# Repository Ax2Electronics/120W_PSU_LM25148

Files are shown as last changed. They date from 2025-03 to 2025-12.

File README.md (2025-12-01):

Schematic Overview(See PDF export for detailed view)


PCB layers


PCB 3D overview





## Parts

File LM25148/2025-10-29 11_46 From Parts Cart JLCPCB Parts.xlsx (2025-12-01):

Parts Type | JLCPCB Part # | MFR Part # | Description | Unit Price | Qty | Total Price
stock | C25803 | 0603WAF1003T5E | -55℃~+155℃ 100kΩ 100mW 75V Thick Film Resistor ±1% ±100ppm/℃ 0603 Chip Resistor - Surface Mount ROHS | 0.001 | 20 | 0.02 | 1 | 5 | 0.005
buy | C2051924 | IHLP3232DZER2R2M5A | 11.5A 11.7mΩ 14A 2.2uH AEC-Q200 ±20% SMD,8.2x8.2mm Power Inductors ROHS | 0.7305 | 12 | 8.77 | 1 | 5 | 3.6525
stock | C89632 | CL31B106KBHNNNE | 10uF 50V X7R ±10% 1206 Multilayer Ceramic Capacitors MLCC - SMD/SMT ROHS | 0.0539 | 54 | 2.92 | 10 | 5 | 2.695
stock | C863129 | RT0603DRE0749K3L | -55℃~+155℃ 100mW 49.3kΩ Thin Film Resistor ±0.5% ±50ppm/℃ 0603 Chip Resistor - Surface Mount ROHS | 0.0064 | 20 | 0.13 | 1 | 5 | 0.032
stock | C7509568 | 2601-1102 | -60℃~+105℃ 0.14~1.5 1 160V 16~26 17.5A 1x2P 2 2P 3.5mm Gray Right Angle 插件,P=3.5mmm Spring Clamp System Terminal Block ROHS | 1.122 | 11 | 12.35 | 2 | 5 | 11.22
stock | C43922 | 0603B225K160NT | 16V 2.2uF X7R ±10% 0603 Multilayer Ceramic Capacitors MLCC - SMD/SMT ROHS | 0.009 | 20 | 0.18 | 2 | 5 | 0.09
stock | C3289501 | SQJ459EP-T1_GE3 | -55℃~+175℃ 1 P-Channel 108nC@10V 18mΩ@10V 2.5V@250uA 27W 312pF 4.586nF 497pF 52A 60V P-Channel PowerPAKSO-8L MOSFETs ROHS | 0.8715 | 5 | 4.36 | 1 | 5 | 4.3575
stock | C3188828 | LM25148RGYR | -40℃~+125℃ 1 2.2MHz 3.5V~42V 800mV~36V 9.5uA Adjustable Buck Buck External Yes VQFN-24(5.5x3.5) DC-DC Converters ROHS | 1.8195 | 5 | 9.1 | 1 | 5 | 9.0975
stock | C29536843 | IAUCN04S7L028ATMA1 | -55℃~+175℃ 1.578nF 1.8V@15uA 100A 2.82mΩ@10V 24nC@10V 36pF 40V 58W 788pF N-Channel TDSON-8 MOSFETs ROHS | 0.732 | 20 | 14.64 | 4 | 5 | 14.64
stock | C2930101 | FRC0603F4122TS | -55℃~+155℃ 100mW 41.2kΩ 75V Thick Film Resistor ±1% ±100ppm/℃ 0603 Chip Resistor - Surface Mount ROHS | 0.001 | 20 | 0.02 | 1 | 5 | 0.005
stock | C2847583 | MDA1365-100M | 10A 10uH 13A 19.2mΩ ±20% SMD,13.5x12.6mm Inductors (SMD) ROHS | 1.0125 | 5 | 5.07 | 1 | 5 | 5.0625
stock | C25962 | 0603WAF2492T5E | -55℃~+155℃ 100mW 24.9kΩ 75V Thick Film Resistor ±1% ±100ppm/℃ 0603 Chip Resistor - Surface Mount ROHS | 0.0011 | 20 | 0.03 | 1 | 5 | 0.0055
stock | C25811 | 0603WAF2003T5E | -55℃~+155℃ 100mW 200kΩ 75V Thick Film Resistor ±1% ±100ppm/℃ 0603 Chip Resistor - Surface Mount ROHS | 0.0011 | 20 | 0.03 | 1 | 5 | 0.0055
stock | C100771 | CR0603FA1432G | -55℃~+125℃ 100mW 14.3kΩ 50V Thick Film Resistor ±1% ±100ppm/℃ 0603 Chip Resistor - Surface Mount ROHS | 0.0007 | 20 | 0.02 | 1 | 5 | 0.0035
stock | C23184 | 0603WAF4992T5E | -55℃~+155℃ 100mW 49.9kΩ 75V Thick Film Resistor ±1% ±100ppm/℃ 0603 Chip Resistor - Surface Mount ROHS | 0.0011 | 20 | 0.03 | 1 | 5 | 0.0055
stock | C224085 | TPSMB33CA | -65℃~+175℃ 12.2uA 1A@10/1000us 28.2V 37.8V 49.9V 600W@10/1000us Bidirectional IEC 61000-4-2 TVS DO-214AA ESD and Surge Protection (TVS/ESD) ROHS | 0.1467 | 5 | 0.74 | 1 | 5 | 0.7335
stock | C21397 | GRM32ER71E226KE15L | 22uF 25V X7R ±10% 1210 Multilayer Ceramic Capacitors MLCC - SMD/SMT ROHS | 0.2037 | 20 | 4.08 | 4 | 5 | 4.074
stock | C19606 | RVT1V331M1010 | -55℃~+105℃ 10.2mm 10mm 2000hrs@105℃ 330uF 35V ±20% SMD,D10xL10.5mm Aluminum Electrolytic Capacitors - SMD ROHS | 0.1091 | 6 | 0.66 | 1 | 5 | 0.5455
stock | C185817 | RLM25FEER005 | 2W 5mΩ Current Sense Resistor Surface Mount ±1% ±50ppm/℃ 2512 Current Sense Resistors / Shunt Resistors ROHS | 0.0458 | 9 | 0.42 | 1 | 5 | 0.229
stock | C17660 | 0805W8F300KT5E | -55℃~+155℃ 125mW 150V 3Ω Thick Film Resistor ±1% ±200ppm/℃ 0805 Chip Resistor - Surface Mount ROHS | 0.003 | 20 | 0.06 | 1 | 5 | 0.015
stock | C17168 | 0402WGF0000TCE | -55℃~+155℃ 0Ω 50V 62.5mW Thick Film Resistor ±1% ±800ppm/℃ 0402 Chip Resistor - Surface Mount ROHS | 0.0005 | 40 | 0.02 | 6 | 5 | 0.015
stock | C1599 | 0603B182K500NT | 1.8nF 50V X7R ±10% 0603 Multilayer Ceramic Capacitors MLCC - SMD/SMT ROHS | 0.003 | 20 | 0.06 | 1 | 5 | 0.015
stock | C1591 | CL10B104KB8NNNC | 100nF 50V X7R ±10% 0603 Multilayer Ceramic Capacitors MLCC - SMD/SMT ROHS | 0.0026 | 70 | 0.19 | 12 | 5 | 0.156
stock | C152458 | BAT54T1G | -55℃~+125℃ 200mA 2uA@25V 30V 600mA 800mV@100mA SOD-123 Schottky Diodes ROHS | 0.0209 | 9 | 0.19 | 1 | 5 | 0.1045
stock | C15177 | CL21B102KCANNNC | 100V 1nF X7R ±10% 0805 Multilayer Ceramic Capacitors MLCC - SMD/SMT ROHS | 0.009 | 20 | 0.18 | 1 | 5 | 0.045
stock | C101063 | CR0603FA4702G | -55℃~+125℃ 100mW 47kΩ 50V Thick Film Resistor ±1% ±100ppm/℃ 0603 Chip Resistor - Surface Mount ROHS | 0.0013 | 20 | 0.03 | 1 | 5 | 0.0065
overseas_shop | C25905937 | A785MN227M1VLAS023 | 220 µF 35 V Aluminum - Polymer Capacitors Radial, Can - SMD 23mOhm 1000 Hrs @ 150°C | 1.0765 | 10 | 10.77 | 2 | 5 | 10.765
overseas_shop | C3735058 | DZ23C15-E3-08 | Zener Diodes 15 Volt 0.3 Watt 5% | 0.0795 | 268 | 21.31 | 1 | 5 | 0.3975
 |  |  |  |  |  |  |  | comp | 67.9785
 |  |  |  |  |  |  |  | pcb | 7
 |  |  |  |  |  |  |  | assy | 30
 |  |  |  |  |  |  |  |  | 104.9785

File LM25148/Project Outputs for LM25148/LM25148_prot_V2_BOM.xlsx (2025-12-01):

DigiKey Part Number | Mouser Part Number | Comment | Description | Designator | Footprint | LibRef | Quantity | Local price | Total | Manufacturer Product Number | ComponentLink1URL | ComponentLink2URL
565-EMZR500ARA331MJA0GCT-ND |  | 330uF | 330 µF 50 V Aluminum Electrolytic Capacitors Radial, Can - SMD 120mOhm @ 100kHz 2000 Hrs @ 105°C | C1 | CAPAE109103X103M | C000026 | 1 | 200 | 200 | EMZR500ARA331MJA0G | https://www.digikey.com/en/products/detail/chemi-con/EMZR500ARA331MJA0G/5824768
1276-6767-1-ND |  | 10uF | 10 µF ±10% 50V Ceramic Capacitor X7R 1206 (3216 Metric) | C2, C3, C4, C5, C9, C14, C16, C34, C35, C36 | CAP_1206 | C000017 | 10 | 30 | 300 | CL31B106KBHNNNE | https://www.digikey.com/en/products/detail/samsung-electro-mechanics/CL31B106KBHNNNE/5961251
1276-1000-1-ND |  | 0.1uF | 0.1 µF ±10% 50V Ceramic Capacitor X7R 0603 (1608 Metric) | C6, C7, C8, C11, C12, C13, C15, C37 | CAP_0603 | C000018 | 8 | 1.68 | 13.44 | CL10B104KB8NNNC | https://www.digikey.com/en/products/detail/samsung-electro-mechanics/CL10B104KB8NNNC/3886658
490-12731-1-ND |  | 2.2uF | 8 pF ±0.05pF 25V Ceramic Capacitor C0G, NP0 01005 (0402 Metric) | C10, C33 | CAP_0603 | C000014 | 2 | 23.48 | 46.96 | GRM188C71C225KE11D | https://www.digikey.com/en/products/detail/murata-electronics/GRM188C71C225KE11D/4905311
478-KAM15AR71E104KTCT-ND |  | 100nF | 0.1 µF ±10% 25V Ceramic Capacitor X7R 0603 (1608 Metric) | C17, C18, C29, C32 | CAP_0603 | C000007 | 4 | 14.04 | 56.16 | KAM15AR71E104KT | https://www.digikey.com/en/products/detail/kyocera-avx/06033C104K4T2A/8019250
1276-3392-1-ND |  | 22uF | 22 µF ±10% 25V Ceramic Capacitor X7R 1210 (3225 Metric) | C19, C20, C21, C22 | CAP_1210 | C000032 | 4 | 70 | 280 | CL32B226KAJNNNE | https://www.digikey.com/en/products/detail/samsung-electro-mechanics/CL32B226KAJNNNE/3889050
399-A785MN227M1VLAS023CT-ND |  | 220uF | 220 µF 35 V Aluminum - Polymer Capacitors Radial, Can - SMD 23mOhm 1000 Hrs @ 150°C | C23, C24 | CAPAE109103X103M | C000033 | 2 | 214 | 428 | A785MN227M1VLAS023 | https://www.digikey.com/en/products/detail/kemet/A785MN227M1VLAS023/22003773
399-15370-1-ND |  | 1.8nF | 1800 pF ±10% 25V Ceramic Capacitor X7R 0603 (1608 Metric) | C30 | CAP_0603 | C000027 | 1 | 31.23 | 31.23 | C0603C182K3RACTU | https://www.digikey.com/en/products/detail/kemet/C0603C182K3RAC7867/2200107
2946-2601-1102-ND |  | TERM BLK PCB LEVER 3.5MM 2POS | 2 Position Wire to Board Terminal Block Horizontal with Board 0.138" (3.50mm) Through Hole | CN1, CN2 | CONN2_2601-1102_WAG | 00000017 | 2 | 500 | 1000 | 2601-1102 | https://www.digikey.com/en/products/detail/wago-corporation/2601-1102/17122694
311-1472-1-ND |  | 1nF | 1000 pF ±10% 100V Ceramic Capacitor X7R 0805 (2012 Metric) | CSN | CAP_0805 | C000035 | 1 | 20 | 20 | CC0805KRX7R0BB102 | https://www.digikey.com/en/products/detail/yageo/CC0805KRX7R0BB102/2833637
296-LM25148RGYRCT-ND | 595-LM25148RGYR | LM25148RGYR 42-V SYNCHRONOUS BUCK DC/DC CONT | Buck Regulator Positive Output Step-Down DC-DC Controller IC 24-VQFN (5.5x3.5) | IC1 | VQFN25_RGY_TEX | LM25148RGYR | 1 | 600 | 600 | LM25148RGYR | https://www.digikey.com/en/products/detail/texas-instruments/LM25148RGYR/15857124 | https://eu.mouser.com/ProductDetail/Texas-Instruments/LM25148RGYR?qs=doiCPypUmgEViljGB5jAZw%3D%3D
541-IHLP3232DZER2R2M5ACT-ND | 70-IHLP3232DZR2R2M5A | 2.2uH | FIXED IND 2.2UH 11.5A 12.5 MOHM | L1 | IHLP-3232DZ-51 | L000015 | 1 | 254.58 | 254.58 | IHLP3232DZER2R2M5A | https://www.digikey.com/en/products/detail/vishay-dale/IHLP3232DZER2R2M5A/4070222 | https://eu.mouser.com/ProductDetail/Vishay-Dale/IHLP3232DZER2R2M5A?qs=tDDpbAIEejr3%252BeiaEh99%252Bg%3D%3D
553-4029-1-ND | 673-PA4343.103ANLT | 10uH | FIXED IND 10UH 11A 15.8 MOHM SMD | L2 | INDP135126X65N | L000016 | 1 | 400 | 400 | PA4343.103ANLT | https://www.digikey.com/en/products/detail/pulse-electronics/PA4343-103ANLT/7943151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 | https://eu.mouser.com/ProductDetail/Pulse-Electronics/PA4343.103ANLT?qs=chTDxNqvsym%252BWuIQdh7qfw%3D%3D
448-IAUCN04S7L028ATMA1CT-ND | 726-IAUCN04S7L028ATM | IAUCN04S7L028ATMA1 | N-Channel 40 V 100A Surface Mount PG-TDSON-8-33 | Q1, Q2, Q3, Q4 | PG-TDSON-8-33 | 00000014 | 4 | 150 | 600 | IAUCN04S7L028ATMA1 | https://www.digikey.com/en/products/detail/infineon-technologies/IAUCN04S7L028ATMA1/22157720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 | https://eu.mouser.com/ProductDetail/Infineon-Technologies/IAUCN04S7L028ATMA1?qs=mELouGlnn3deeHozE86VbA%3D%3D
SQJ459EP-T1_GE3CT-ND | 78-SQJ459EP-T2_BE3 | SQJ659EP PMOS | P-Channel 60 V 52A (Tc) 83W (Tc) Surface Mount PowerPAK® SO-8 | Q_RP | PowerPAK SO-8L SINGLE | 00000005 | 1 | 310.22 | 310.22 | SQJ459EP-T1_GE3 | https://www.digikey.com/en/products/detail/vishay-siliconix/SQJ459EP-T1-GE3/6708881 | https://eu.mouser.com/ProductDetail/Vishay-Siliconix/SQJ459EP-T2_BE3?qs=CiayqK2gdcKpg8h0vLRPjA%3D%3D
541-49.9KHCT-ND |  | 49.9kOhm | 49.9 kOhms ±1% 0.1W, 1/10W Chip Resistor 0603 (1608 Metric) Moisture Resistant Thick Film | R2 | RES_0603 | R000025 | 1 | 2.10 | 2.1 | CRCW060349K9FKEA | https://www.digikey.com/en/products/detail/vishay-dale/CRCW060349K9FKEA/1180003
CRF2512-FZ-R005ELFCT-ND |  | 5mOhm | 5 mOhms ±1% 2W Chip Resistor 2512 (6332 Metric) Automotive AEC-Q200, Current Sense, Moisture Resistant Metal Element | R4 | SENSE_RES_2512 | R000033 | 1 | 150 | 150 | CRF2512-FZ-R005ELF | https://www.digikey.com/en/products/detail/bourns-inc/CRF2512-FZ-R005ELF/6210986
P24.9KHCT-ND |  | 24.9kOhm | 24.9 kOhms ±1% 0.1W, 1/10W Chip Resistor 0603 (1608 Metric) Automotive AEC-Q200 Thick Film | R6 | RES_0603 | R000017 | 1 | 6.92 | 6.92 | ERJ-3EKF2492V | https://www.digikey.com/en/products/detail/panasonic-electronic-components/ERJ-3EKF2492V/196236
P0.0JCT-ND |  | 0 Ohm Jump | 0 Ohms Jumper Chip Resistor 0402 (1005 Metric) Automotive AEC-Q200 Thick Film | R8, R10, RQ1, RQ2, RQ3, RQ4 | RES_0402 | R000008 | 6 | 2.10 | 12.6 | ERJ-2GE0R00X | https://www.digikey.com/en/products/detail/panasonic-electronic-components/ERJ-2GE0R00X/146727
RMCF0603FG100KCT-ND |  | 100kOhm | 100 kOhms ±1% 0.1W, 1/10W Chip Resistor 0603 (1608 Metric) Automotive AEC-Q200 Thick Film | R9 | RES_0603 | R000006 | 1 | 3.98 | 3.98 | RMCF0603FG100K | https://www.digikey.com/en/products/detail/stackpole-electronics-inc/RMCF0603FG100K/1713543
P41.2KHCT-ND |  | 41.2kOhm | 41.2 kOhms ±1% 0.1W, 1/10W Chip Resistor 0603 (1608 Metric) Automotive AEC-Q200 Thick Film | R11 | RES_0603 | R000015 | 1 | 6.92 | 6.92 | ERJ-3EKF4122V | https://www.digikey.com/en/products/detail/panasonic-electronic-components/ERJ-3EKF4122V/196347
13-RT0603BRD0749K3LCT-ND |  | 49.3kOhm | 49.3 kOhms ±0.1% 0.1W, 1/10W Chip Resistor 0603 (1608 Metric) Thin Film | R12 | RES_0603 | R000023 | 1 | 21.59 | 21.59 | RT0603BRD0749K3L | https://www.digikey.com/en/products/detail/yageo/RT0603BRD0749K3L/5927964
311-47.0KHRCT-ND |  | 47kOhm | 47 kOhms ±1% 0.1W, 1/10W Chip Resistor 0603 (1608 Metric) Moisture Resistant Thick Film | R_RP | RES_0603 | R000010 | 1 | 1.47 | 1.47 | RC0603FR-0747KL | https://www.digikey.com/en/products/detail/yageo/RC0603FR-0747KL/727253
311-3.00CRCT-ND |  | 3 Ohm | 3 Ohms ±1% 0.125W, 1/8W Chip Resistor 0805 (2012 Metric) Moisture Resistant Thick Film | RSN | RES_0805 | R000034 | 1 | 7 | 7 | RC0805FR-073RL | https://www.digikey.com/en/products/detail/yageo/RC0805FR-073RL/727799
311-200KHRCT-ND |  | 200kOhm | 200 kOhms ±1% 0.1W, 1/10W Chip Resistor 0603 (1608 Metric) Moisture Resistant Thick Film | RUV1 | RES_0603 | R000031 | 1 | 7 | 7 | RC0603FR-07200KL | https://www.digikey.com/en/products/detail/yageo/RC0603FR-07200KL/727044
RMCF0603FT14K3CT-ND |  | 14.3kOhm | 14.3 kOhms ±1% 0.1W, 1/10W Chip Resistor 0603 (1608 Metric) Automotive AEC-Q200 Thick Film | RUV2 | RES_0603 | R000032 | 1 | 7 | 7 | RMCF0603FT14K3 | https://www.digikey.com/en/products/detail/stackpole-electronics-inc/RMCF0603FT14K3/1761296
BAT54T1GOSCT-ND |  | BAT54T1G Schottky | Diode 30 V 200mA Surface Mount SOD-123 | SD1 | SODFL371X135-2N | 00000009 | 1 | 30 | 30 | BAT54T1G | https://www.digikey.com/en/products/detail/onsemi/BAT54T1G/918319
F6323CT-ND |  | TPSMB33CA | 45.7V Clamp 13.3A Ipp Tvs Diode Surface Mount DO-214AA (SMBJ) | TVS1 | DO-214AA | 00000015 | 1 | 70 | 70 | TPSMB33CA | https://www.digikey.com/en/products/detail/littelfuse-inc/TPSMB33CA/4835275
112-DZ23C15-E3-08CT-ND |  | DZ23C15-E3-08 Zener Diode | Zener Diode Array 1 Pair Common Cathode 15 V 300 mW ±5% SOT-23-3 | ZD_RP | SOT95P245X96-3N | 00000006 | 1 | 23.48 | 23.48 | DZ23C15-E3-08 | https://www.digikey.com/en/products/detail/vishay-general-semiconductor-diodes-division/DZ23C15-E3-08/4831460
 |  |  |  |  |  |  |  | Total one PCB | 4890.65
 |  |  |  |  |  |  | 62 | These prices are estimated - not yet officialy confirmed

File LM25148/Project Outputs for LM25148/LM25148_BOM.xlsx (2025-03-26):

Comment | Description | Designator | Footprint | LibRef | Quantity | DigiKey part number | Mouser Part Number | ComponentLink1Description | ComponentLink1URL | ComponentLink2Description | ComponentLink2URL
220uF | 220 µF 35 V Aluminum - Polymer Capacitors Radial, Can - SMD 23mOhm 1000 Hrs @ 150°C | C1 | CAPAE109103X103M | C000033 | 1 | 399-A785MN227M1VLAS023CT-ND |  | digikey | https://www.digikey.com/en/products/detail/kemet/A785MN227M1VLAS023/22003773
10uF | CAP CER 10UF 50V X7R 1206 | C2, C3, C4, C5, C9, C14 | CAP_1206 | C000017 | 6 | 1276-6767-1-ND |  | DigiKey | https://www.digikey.com/en/products/detail/samsung-electro-mechanics/CL31B106KBHNNNE/5961251
0.1uF | CAP CER 0.1UF 50V X7R 0603 | C6, C7, C8, C11, C12, C13, C15 | CAP_0603 | C000018 | 7 | 1276-1000-1-ND |  | DigiKey | https://www.digikey.com/en/products/detail/samsung-electro-mechanics/CL10B104KB8NNNC/3886658
2.2uF | CAP CER 2.2UF 16V X7S 0603 | C10, C33 | CAP_0603 | C000014 | 2 | 490-12731-1-ND |  | Digikey | https://www.digikey.com/en/products/detail/murata-electronics/GRM188C71C225KE11D/4905311
10nf | CAP CER 10nF 0603 25V X7R | C16 | CAP_0603 | C000005 | 1 |  |  | digikey | https://www.digikey.com/en/products/detail/kyocera-avx/06033C103MAT2A/1599370
100nf | CAP CER 100nF 0603 25V X7R | C17, C18, C29, C32 | CAP_0603 | C000007 | 4 |  |  | digikey | https://www.digikey.com/en/products/detail/kyocera-avx/06033C104K4T2A/8019250
22uF | 22 µF ±10% 25V Ceramic Capacitor X7R 1210 (3225 Metric) | C19, C20, C21, C22, C23, C24, C25, C26, C27, C28 | CAP_1210 | C000032 | 10 | 1276-3392-1-ND |  | DigiKey | https://www.digikey.com/en/products/detail/samsung-electro-mechanics/CL32B226KAJNNNE/3889050
1.8nF | 1800 pF ±10% 25V Ceramic Capacitor X7R 0603 (1608 Metric) | C30 | CAP_0603 | C000027 | 1 | 399-15370-1-ND |  | digikey | https://www.digikey.com/en/products/detail/kemet/C0603C182K3RAC7867/2200107
LM25148RGYR 42-V SYNCHRONOUS BUCK DC/DC CONT | Buck Regulator Positive Output Step-Down DC-DC Controller IC 24-VQFN (5.5x3.5) | IC1 | VQFN25_RGY_TEX | LM25148RGYR | 1 | 296-LM25148RGYRCT-ND | 595-LM25148RGYR | DigiKey | https://www.digikey.com/en/products/detail/texas-instruments/LM25148RGYR/15857124 | Mouser | https://eu.mouser.com/ProductDetail/Texas-Instruments/LM25148RGYR?qs=doiCPypUmgEViljGB5jAZw%3D%3D
Header 4 PIN | Header 4 PIN | J1 | HEADER_4PIN | 00000004 | 1
2.2uH | FIXED IND 2.2UH 11.5A 12.5 MOHM | L1 | IHLP-3232DZ-51 | L000015 | 1 | 541-IHLP3232DZER2R2M5ACT-ND | 70-IHLP3232DZR2R2M5A | DigiKey | https://www.digikey.com/en/products/detail/vishay-dale/IHLP3232DZER2R2M5A/4070222 | Mouser | https://eu.mouser.com/ProductDetail/Vishay-Dale/IHLP3232DZER2R2M5A?qs=tDDpbAIEejr3%252BeiaEh99%252Bg%3D%3D
10uH | FIXED IND 10UH 11A 15.8 MOHM SMD | L2 | INDP135126X65N | L000016 | 1 | 553-4029-1-ND | 673-PA4343.103ANLT | DigiKey | https://www.digikey.com/en/products/detail/pulse-electronics/PA4343-103ANLT/7943151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 | Mouser | https://eu.mouser.com/ProductDetail/Pulse-Electronics/PA4343.103ANLT?qs=chTDxNqvsym%252BWuIQdh7qfw%3D%3D
Mounting Hole | Mounting Hole 3mm | MH1, MH2, MH3, MH4 | HOLE-3mm | 00000006 | 4
Terminal Block | Terminal block 90 deg 5mm 2PIN | P1, P2 | TERM_BLOCK 5mm 2PIN | 00000001 | 2 | 2057-EB20-02-C-ND |  | DigiKey | https://www.digikey.com/en/products/detail/adam-tech/EB20-02-C/9831508
IAUC80N04S6L032ATMA1 | N-Channel 40 V 80A (Tc) 50W (Tc) Surface Mount PG-TDSON-8 | Q1, Q2 | PG-TDSON-8-33 | 00000008 | 2 | 448-IAUC80N04S6L032ATMA1CT-ND | 726-IAUC80N04S6L032A | DigiKey | https://www.digikey.com/en/products/detail/infineon-technologies/IAUC80N04S6L032ATMA1/13677609 | Mouser | https://eu.mouser.com/ProductDetail/Infineon-Technologies/IAUC80N04S6L032ATMA1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
SQJ659EP PMOS | P-Channel 60 V 52A (Tc) 83W (Tc) Surface Mount PowerPAK® SO-8 | Q_RP | PowerPAK SO-8L SINGLE | 00000005 | 1 | SQJ459EP-T1_GE3CT-ND | 78-SQJ459EP-T2_BE3 | DigiKey | https://www.digikey.com/en/products/detail/vishay-siliconix/SQJ459EP-T1-GE3/6708881 | Mouser | https://eu.mouser.com/ProductDetail/Vishay-Siliconix/SQJ459EP-T2_BE3?qs=CiayqK2gdcKpg8h0vLRPjA%3D%3D
0 Ohm Jump | RES SMD 0 OHM JUMPER 1/10W 0402 | R1, R7, R8, R10 | RES_0402 | R000008 | 4 | P0.0JCT-ND |  | DigiKey | https://www.digikey.com/en/products/detail/panasonic-electronic-components/ERJ-2GE0R00X/146727
49.9kOhm | 49.9 kOhms ±1% 0.1W, 1/10W Chip Resistor 0603 (1608 Metric) Moisture Resistant Thick Film | R2 | RES_0603 | R000025 | 1 | 311-49.9KHRCT-ND |  | DigiKey | https://www.digikey.com/en/products/detail/yageo/RC0603FR-0749K9L/727265
1Kohm | RES 1K OHM 1% 1/10W 0603 | R3 | RES_0603 | R000004 | 1 |  |  | digikey | https://www.digikey.com/en/products/detail/vishay-beyschlag-draloric-bc-components/MCT06030C1001FP500/2607821
5mOhm | 5 mOhms ±1% 2W Chip Resistor Wide 2010 (5025 Metric), 1020 Anti-Sulfur, Automotive AEC-Q200, Current Sense, Moisture Resistant, Pulse Withstanding Metal Element | R4 | RES_1020_WIDE | R000026 | 1 | 541-10046-1-ND |  | DigiKey | https://www.digikey.com/en/products/detail/vishay-dale/WSL10205L000FEA/9758314
10Kohm | RES 10K OHM 1% 1/10W 0603 | R5 | RES_0603 | R000001 | 1 |  |  | digikey | https://www.digikey.com/en/products/detail/vishay-beyschlag-draloric-bc-components/MCT06030C1002FP500/1850440
24.9kOhm | 24.9 kOhms ±1% 0.1W, 1/10W Chip Resistor 0603 (1608 Metric) Automotive AEC-Q200 Thick Film | R6 | RES_0603 | R000017 | 1 | P24.9KHCT-ND |  | DigiKey | https://www.digikey.com/en/products/detail/panasonic-electronic-components/ERJ-3EKF2492V/196236
100Kohm | RES 100K OHM 1% 1/10W 0603 | R9 | RES_0603 | R000006 | 1 |  |  | digikey | https://www.digikey.com/en/products/detail/stackpole-electronics-inc/RMCF0603FG100K/1713543
41.2kOhm | 41.2 kOhms ±1% 0.1W, 1/10W Chip Resistor 0603 (1608 Metric) Automotive AEC-Q200 Thick Film | R11 | RES_0603 | R000015 | 1 | P41.2KHCT-ND |  | DigiKey | https://www.digikey.com/en/products/detail/panasonic-electronic-components/ERJ-3EKF4122V/196347
43.3kOhm | 49.3 kOhms ±0.1% 0.1W, 1/10W Chip Resistor 0603 (1608 Metric) Thin Film | R12 | RES_0603 | R000023 | 1 | 13-RT0603BRD0749K3LCT-ND |  | DigiKey | https://www.digikey.com/en/products/detail/yageo/RT0603BRD0749K3L/5927964
0 OHM Jump | RES 0 OHM JUMPER 1/10W 0603 | R14 | RES_0603 | R000007 | 1 |  |  | DigiKey | https://www.digikey.com/en/products/detail/stackpole-electronics-inc/RMCF0603ZT0R00/1756908
0.2Ohm | 200 mOhms ±1% 0.5W, 1/2W Chip Resistor 1206 (3216 Metric) Current Sense Thick Film | R15 | RES_1206 | R000024 | 1 | CSR1206FKR200CT-ND |  | DigiKey | https://www.digikey.com/en/products/detail/stackpole-electronics-inc/CSR1206FKR200/1742391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
47kOhm | 47 kOhms ±1% 0.1W, 1/10W Chip Resistor 0603 (1608 Metric) Moisture Resistant Thick Film | R_RP | RES_0603 | R000010 | 1 | 311-47.0KHRCT-ND |  | DigiKey | https://www.digikey.com/en/products/detail/yageo/RC0603FR-0747KL/727253
Test point | Test point 1mm | TP1, TP2, TP3, TP4, TP5, TP6, TP7, TP9, TP10, TP11, TP12, TP13, TP14, TP16, TP17, TP18 | TestPoint | TP002 | 16
DZ23C15-E3-08 Zener Diode | Zener Diode Array 1 Pair Common Cathode 15 V 300 mW ±5% SOT-23-3 | ZD_RP | SOT95P245X96-3N | 00000006 | 1 | 112-DZ23C15-E3-08CT-ND |  | DigiKey | https://www.digikey.com/en/products/detail/vishay-general-semiconductor-diodes-division/DZ23C15-E3-08/4831460

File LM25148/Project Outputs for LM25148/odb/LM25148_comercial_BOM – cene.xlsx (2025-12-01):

Comment | Description | Designator | Footprint | LibRef | Quantity | ComponentLink1URL | ComponentLink2URL | MOUSER Part Number | Digikey Part Number
220uF | 220 µF 35 V Aluminum - Polymer Capacitors Radial, Can - SMD 23mOhm 1000 Hrs @ 150°C | C1 | CAPAE109103X103M | C000033 | 1 | https://www.digikey.com/en/products/detail/kemet/A785MN227M1VLAS023/22003773 |  |  | 399-A785MN227M1VLAS023CT-ND | 0.6255000000 | 5 | 3.1275
10uF | 10 µF ±10% 50V Ceramic Capacitor X7R 1206 (3216 Metric) | C2, C3, C4, C5, C9, C14, C16, C34, C35, C36 | CAP_1206 | C000017 | 10 | https://www.digikey.com/en/products/detail/samsung-electro-mechanics/CL31B106KBHNNNE/5961251 |  |  | 1276-6767-1-ND | 0.0545000000 | 5 | 2.725
0.1uF | 0.1 µF ±10% 50V Ceramic Capacitor X7R 0603 (1608 Metric) | C6, C7, C8, C11, C12, C13, C15 | CAP_0603 | C000018 | 7 | https://www.digikey.com/en/products/detail/samsung-electro-mechanics/CL10B104KB8NNNC/3886658 |  |  | 1276-1000-1-ND | 0.0025000000 | 5 | 0.0875
2.2uF | 8 pF ±0.05pF 25V Ceramic Capacitor C0G, NP0 01005 (0402 Metric) | C10, C33 | CAP_0603 | C000014 | 2 | https://www.digikey.com/en/products/detail/murata-electronics/GRM188C71C225KE11D/4905311 |  |  | 490-12731-1-ND | 0.0554000000 | 5 | 0.554
100nf | 0.1 µF ±10% 25V Ceramic Capacitor X7R 0603 (1608 Metric) | C17, C18, C29, C32 | CAP_0603 | C000007 | 4 | https://www.digikey.com/en/products/detail/kyocera-avx/06033C104K4T2A/8019250 |  |  | 478-KAM15AR71E104KTCT-ND | 0.0025000000 | 5 | 0.05
22uF | 22 µF ±10% 25V Ceramic Capacitor X7R 1210 (3225 Metric) | C19, C20, C21, C22, C23, C24, C25, C26, C27, C28 | CAP_1210 | C000032 | 10 | https://www.digikey.com/en/products/detail/samsung-electro-mechanics/CL32B226KAJNNNE/3889050 |  |  | 1276-3392-1-ND | 0.0921000000 | 5 | 4.605
1.8nF | 1800 pF ±10% 25V Ceramic Capacitor X7R 0603 (1608 Metric) | C30 | CAP_0603 | C000027 | 1 | https://www.digikey.com/en/products/detail/kemet/C0603C182K3RAC7867/2200107 |  |  | 399-15370-1-ND | 0.0204000000 | 5 | 0.102
TERM BLK PCB LEVER 3.5MM 2POS | 2 Position Wire to Board Terminal Block Horizontal with Board 0.138" (3.50mm) Through Hole | CN1, CN2 | CONN2_2601-1102_WAG | 00000017 | 2 | https://www.digikey.com/en/products/detail/wago-corporation/2601-1102/17122694 |  |  | 2946-2601-1102-ND | 1.1220000000 | 5 | 11.22
LM25148RGYR 42-V SYNCHRONOUS BUCK DC/DC CONT | Buck Regulator Positive Output Step-Down DC-DC Controller IC 24-VQFN (5.5x3.5) | IC1 | VQFN25_RGY_TEX | LM25148RGYR | 1 | https://www.digikey.com/en/products/detail/texas-instruments/LM25148RGYR/15857124 | https://eu.mouser.com/ProductDetail/Texas-Instruments/LM25148RGYR?qs=doiCPypUmgEViljGB5jAZw%3D%3D | 595-LM25148RGYR | 296-LM25148RGYRCT-ND | 1.7040000000 | 5 | 8.52
2.2uH | FIXED IND 2.2UH 11.5A 12.5 MOHM | L1 | IHLP-3232DZ-51 | L000015 | 1 | https://www.digikey.com/en/products/detail/vishay-dale/IHLP3232DZER2R2M5A/4070222 | https://eu.mouser.com/ProductDetail/Vishay-Dale/IHLP3232DZER2R2M5A?qs=tDDpbAIEejr3%252BeiaEh99%252Bg%3D%3D | 70-IHLP3232DZR2R2M5A | 541-IHLP3232DZER2R2M5ACT-ND | 0.7305000000 | 5 | 3.6525
10uH | FIXED IND 10UH 11A 15.8 MOHM SMD | L2 | INDP135126X65N | L000016 | 1 | https://www.digikey.com/en/products/detail/pulse-electronics/PA4343-103ANLT/7943151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 | https://eu.mouser.com/ProductDetail/Pulse-Electronics/PA4343.103ANLT?qs=chTDxNqvsym%252BWuIQdh7qfw%3D%3D | 673-PA4343.103ANLT | 553-4029-1-ND | 0.8145000000 | 5 | 4.0725
Mounting Hole | Mounting Hole 3mm | MH1, MH2, MH3, MH4 | HOLE-3mm | 00000006 | 4 |  |  |  |  |  |  | 0
IAUC80N04S6L032ATMA1 | N-Channel 40 V 80A (Tc) 50W (Tc) Surface Mount PG-TDSON-8 | Q1, Q2 | PG-TDSON-8-33 | 00000008 | 2 | https://www.digikey.com/en/products/detail/infineon-technologies/IAUC80N04S6L032ATMA1/13677609 | https://eu.mouser.com/ProductDetail/Infineon-Technologies/IAUC80N04S6L032ATMA1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 | 726-IAUC80N04S6L032A | 448-IAUC80N04S6L032ATMA1CT-ND | 0.4935000000 | 5 | 4.935
SQJ659EP PMOS | P-Channel 60 V 52A (Tc) 83W (Tc) Surface Mount PowerPAK® SO-8 | Q_RP | PowerPAK SO-8L SINGLE | 00000005 | 1 | https://www.digikey.com/en/products/detail/vishay-siliconix/SQJ459EP-T1-GE3/6708881 | https://eu.mouser.com/ProductDetail/Vishay-Siliconix/SQJ459EP-T2_BE3?qs=CiayqK2gdcKpg8h0vLRPjA%3D%3D | 78-SQJ459EP-T2_BE3 | SQJ459EP-T1_GE3CT-ND | 0.9030000000 | 5 | 4.515
49.9kOhm | 49.9 kOhms ±1% 0.1W, 1/10W Chip Resistor 0603 (1608 Metric) Moisture Resistant Thick Film | R2 | RES_0603 | R000025 | 1 | https://www.digikey.com/en/products/detail/yageo/RC0603FR-0749K9L/727265 |  |  | 311-49.9KHRCT-ND | 0.0060000000 | 5 | 0.03
5mOhm | 5 mOhms ±1% 2W Chip Resistor Wide 2010 (5025 Metric), 1020 Anti-Sulfur, Automotive AEC-Q200, Current Sense, Moisture Resistant, Pulse Withstanding Metal Element | R4 | RES_1020_WIDE | R000026 | 1 | https://www.digikey.com/en/products/detail/vishay-dale/WSL10205L000FEA/9758314 |  |  | 541-10046-1-ND | 0.3000000000 | 5 | 1.5
24.9kOhm | 24.9 kOhms ±1% 0.1W, 1/10W Chip Resistor 0603 (1608 Metric) Automotive AEC-Q200 Thick Film | R6 | RES_0603 | R000017 | 1 | https://www.digikey.com/en/products/detail/panasonic-electronic-components/ERJ-3EKF2492V/196236 |  |  | P24.9KHCT-ND | 0.0053000000 | 5 | 0.0265
0 Ohm Jump | 0 Ohms Jumper Chip Resistor 0402 (1005 Metric) Automotive AEC-Q200 Thick Film | R8, R10 | RES_0402 | R000008 | 2 | https://www.digikey.com/en/products/detail/panasonic-electronic-components/ERJ-2GE0R00X/146727 |  |  | P0.0JCT-ND | 0.0043000000 | 5 | 0.043
100Kohm | 100 kOhms ±1% 0.1W, 1/10W Chip Resistor 0603 (1608 Metric) Automotive AEC-Q200 Thick Film | R9 | RES_0603 | R000006 | 1 | https://www.digikey.com/en/products/detail/stackpole-electronics-inc/RMCF0603FG100K/1713543 |  |  | RMCF0603FG100KCT-ND | 0.0033000000 | 5 | 0.0165
41.2kOhm | 41.2 kOhms ±1% 0.1W, 1/10W Chip Resistor 0603 (1608 Metric) Automotive AEC-Q200 Thick Film | R11 | RES_0603 | R000015 | 1 | https://www.digikey.com/en/products/detail/panasonic-electronic-components/ERJ-3EKF4122V/196347 |  |  | P41.2KHCT-ND | 0.0050000000 | 5 | 0.025
49.3kOhm | 49.3 kOhms ±0.1% 0.1W, 1/10W Chip Resistor 0603 (1608 Metric) Thin Film | R12 | RES_0603 | R000023 | 1 | https://www.digikey.com/en/products/detail/yageo/RT0603BRD0749K3L/5927964 |  |  | 13-RT0603BRD0749K3LCT-ND | 0.0060000000 | 5 | 0.03
0.2Ohm | 200 mOhms ±1% 0.5W, 1/2W Chip Resistor 1206 (3216 Metric) Current Sense Thick Film | R15 | RES_1206 | R000024 | 1 | https://www.digikey.com/en/products/detail/stackpole-electronics-inc/CSR1206FKR200/1742391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 |  |  | CSR1206FKR200CT-ND | 0.0653000000 | 5 | 0.3265
47kOhm | 47 kOhms ±1% 0.1W, 1/10W Chip Resistor 0603 (1608 Metric) Moisture Resistant Thick Film | R_RP | RES_0603 | R000010 | 1 | https://www.digikey.com/en/products/detail/yageo/RC0603FR-0747KL/727253 |  |  | 311-47.0KHRCT-ND | 0.0011000000 | 5 | 0.0055
200kOhm | 200 kOhms ±1% 0.1W, 1/10W Chip Resistor 0603 (1608 Metric) Moisture Resistant Thick Film | RUV1 | RES_0603 | R000031 | 1 | https://www.digikey.com/en/products/detail/yageo/RC0603FR-07200KL/727044 |  |  | 311-200KHRCT-ND | 0.0011000000 | 5 | 0.0055
14.3kOhm | 14.3 kOhms ±1% 0.1W, 1/10W Chip Resistor 0603 (1608 Metric) Automotive AEC-Q200 Thick Film | RUV2 | RES_0603 | R000032 | 1 | https://www.digikey.com/en/products/detail/stackpole-electronics-inc/RMCF0603FT14K3/1761296 |  |  | RMCF0603FT14K3CT-ND | 0.0020000000 | 5 | 0.01
BAT54T1G Schottky | Diode 30 V 200mA Surface Mount SOD-123 | SD1 | SODFL371X135-2N | 00000009 | 1 | https://www.digikey.com/en/products/detail/onsemi/BAT54T1G/918319 |  |  | BAT54T1GOSCT-ND | 0.0312000000 | 5 | 0.156
Test point | Test point 1mm | TP1, TP2, TP3, TP4, TP6, TP7, TP9, TP10, TP11, TP13, TP16, TP17 | TestPoint | TP002 | 12 |  |  |  |  |  |  | 0
DZ23C15-E3-08 Zener Diode | Zener Diode Array 1 Pair Common Cathode 15 V 300 mW ±5% SOT-23-3 | ZD_RP | SOT95P245X96-3N | 00000006 | 1 | https://www.digikey.com/en/products/detail/vishay-general-semiconductor-diodes-division/DZ23C15-E3-08/4831460 |  |  | 112-DZ23C15-E3-08CT-ND | 0.0152000000 | 5 | 0.076
 |  |  |  |  |  |  |  |  |  |  |  | 50.4165
 |  |  |  |  |  |  |  |  |  |  | PCB cost | 7
 |  |  |  |  |  |  |  |  |  |  | ASS cost | 30
 |  |  |  |  |  |  |  |  |  |  | 5 assembled PCBs | 87.4165

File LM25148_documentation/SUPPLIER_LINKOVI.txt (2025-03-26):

DigiKey:
https://www.digikey.com/en/products/detail/texas-instruments/LM25148RGYR/15857124

Mouser:
https://eu.mouser.com/ProductDetail/Texas-Instruments/LM25148QRGYRQ1?qs=Jm2GQyTW%2FbhVkeoBttDkQw%3D%3D

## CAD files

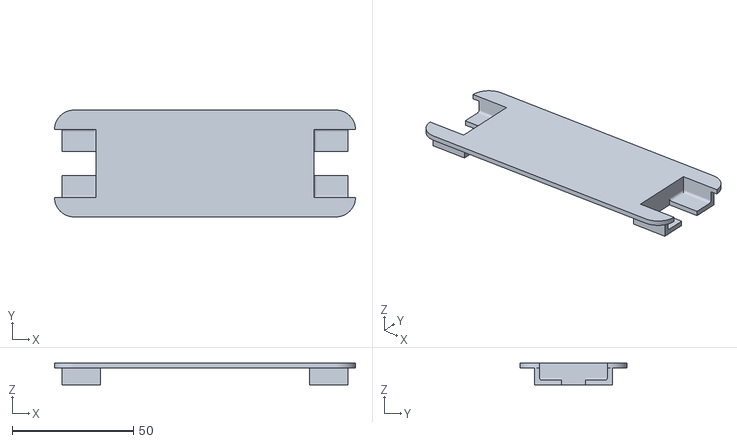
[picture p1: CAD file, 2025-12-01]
3D_models/case_top_cover_v1.1.stl
124.0 x 44.0 x 9.00

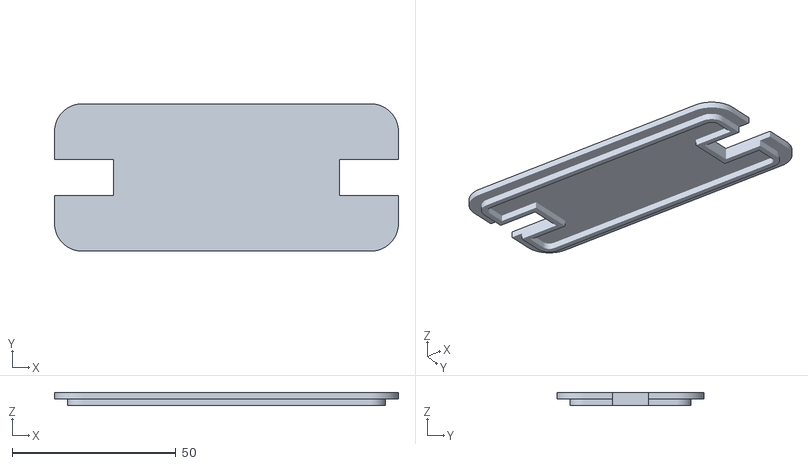
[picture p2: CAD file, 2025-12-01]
LM25148/120W_PSU_case_top_cover.stl
105.0 x 45.0 x 4.00

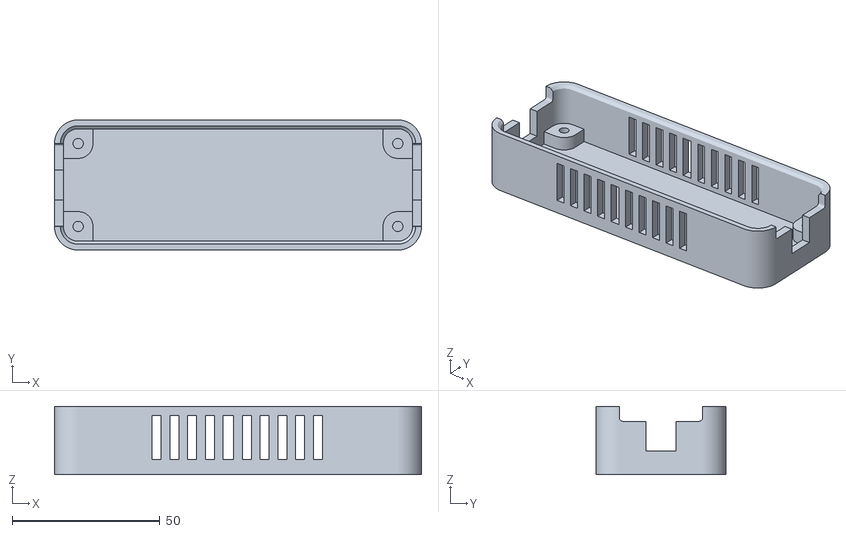
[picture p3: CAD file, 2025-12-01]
3D_models/case_foundation_v1.1.stl
124.0 x 44.0 x 23.0

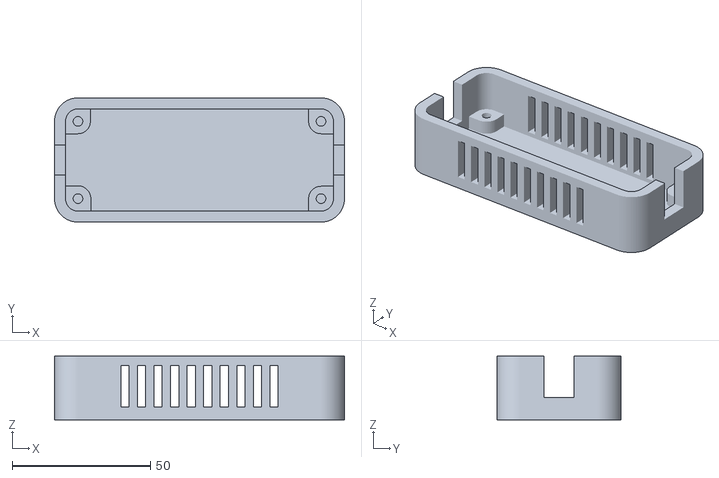
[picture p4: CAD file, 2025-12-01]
LM25148/120W_PSU_case_foundation.stl
105.0 x 45.0 x 23.0

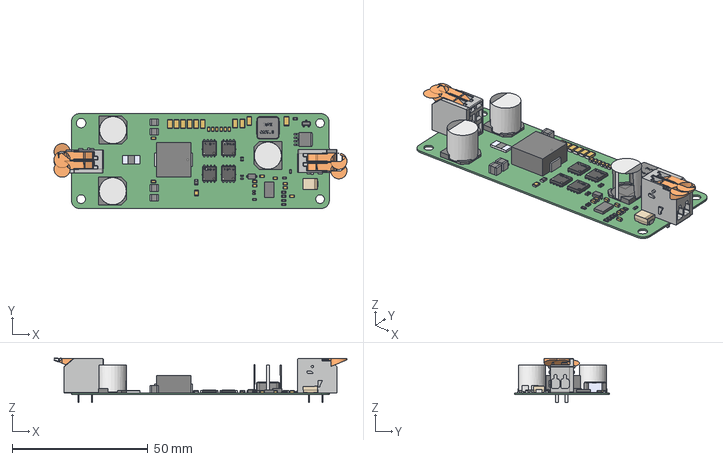
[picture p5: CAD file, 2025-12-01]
LM25148/LM25148_V2.step
107.9 x 34.9 x 16.4 mm

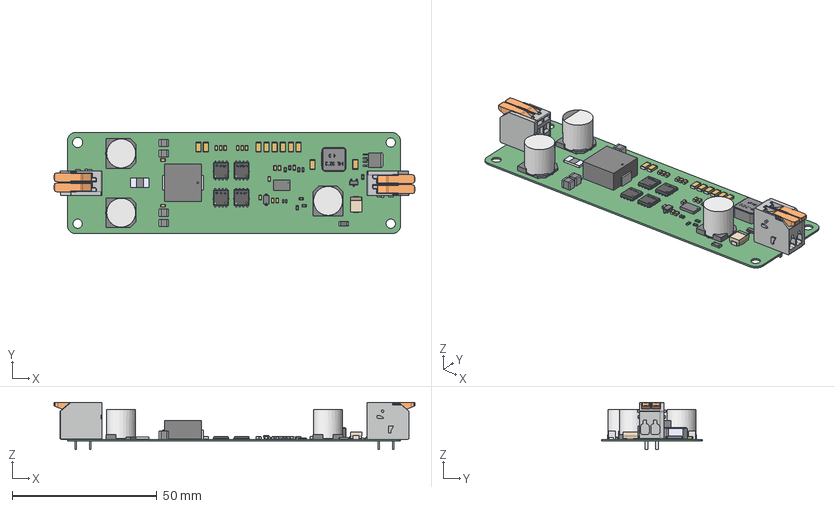
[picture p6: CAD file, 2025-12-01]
LM25148/LM25148.step
124.5 x 34.9 x 16.4 mm
lead x 6
MSAST32MAB5476MPNDT1 x 4
TPSMBSeries_LTF
PG-TDSON-8-33_Lower Mold x 4
PG-TDSON-8-33_Upper Mold x 4
PG-TDSON-8-33_Exposed Lead 1 x 4
PG-TDSON-8-33_Exposed Lead 2 x 4
PG-TDSON-8-33_Exposed Lead 3 x 4
PG-TDSON-8-33_Infineon LOGO x 4
User Library-CR1608-0603 x 8
Leader x 3
SOD-123_ONS
User Library-CR3216-1206
TO_0EP-T1_BE3_VIS
IND_PA4343_FOOTPRINT2_PUL
BODY IHLP3232X400
CLIP 400 x 2
CCS_CCSTDNOS_0402_L1.05W0.55T0.55B0.3 x 2

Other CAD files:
3D_models/case_top_cover.stl
3D_models/case_foundation.stl

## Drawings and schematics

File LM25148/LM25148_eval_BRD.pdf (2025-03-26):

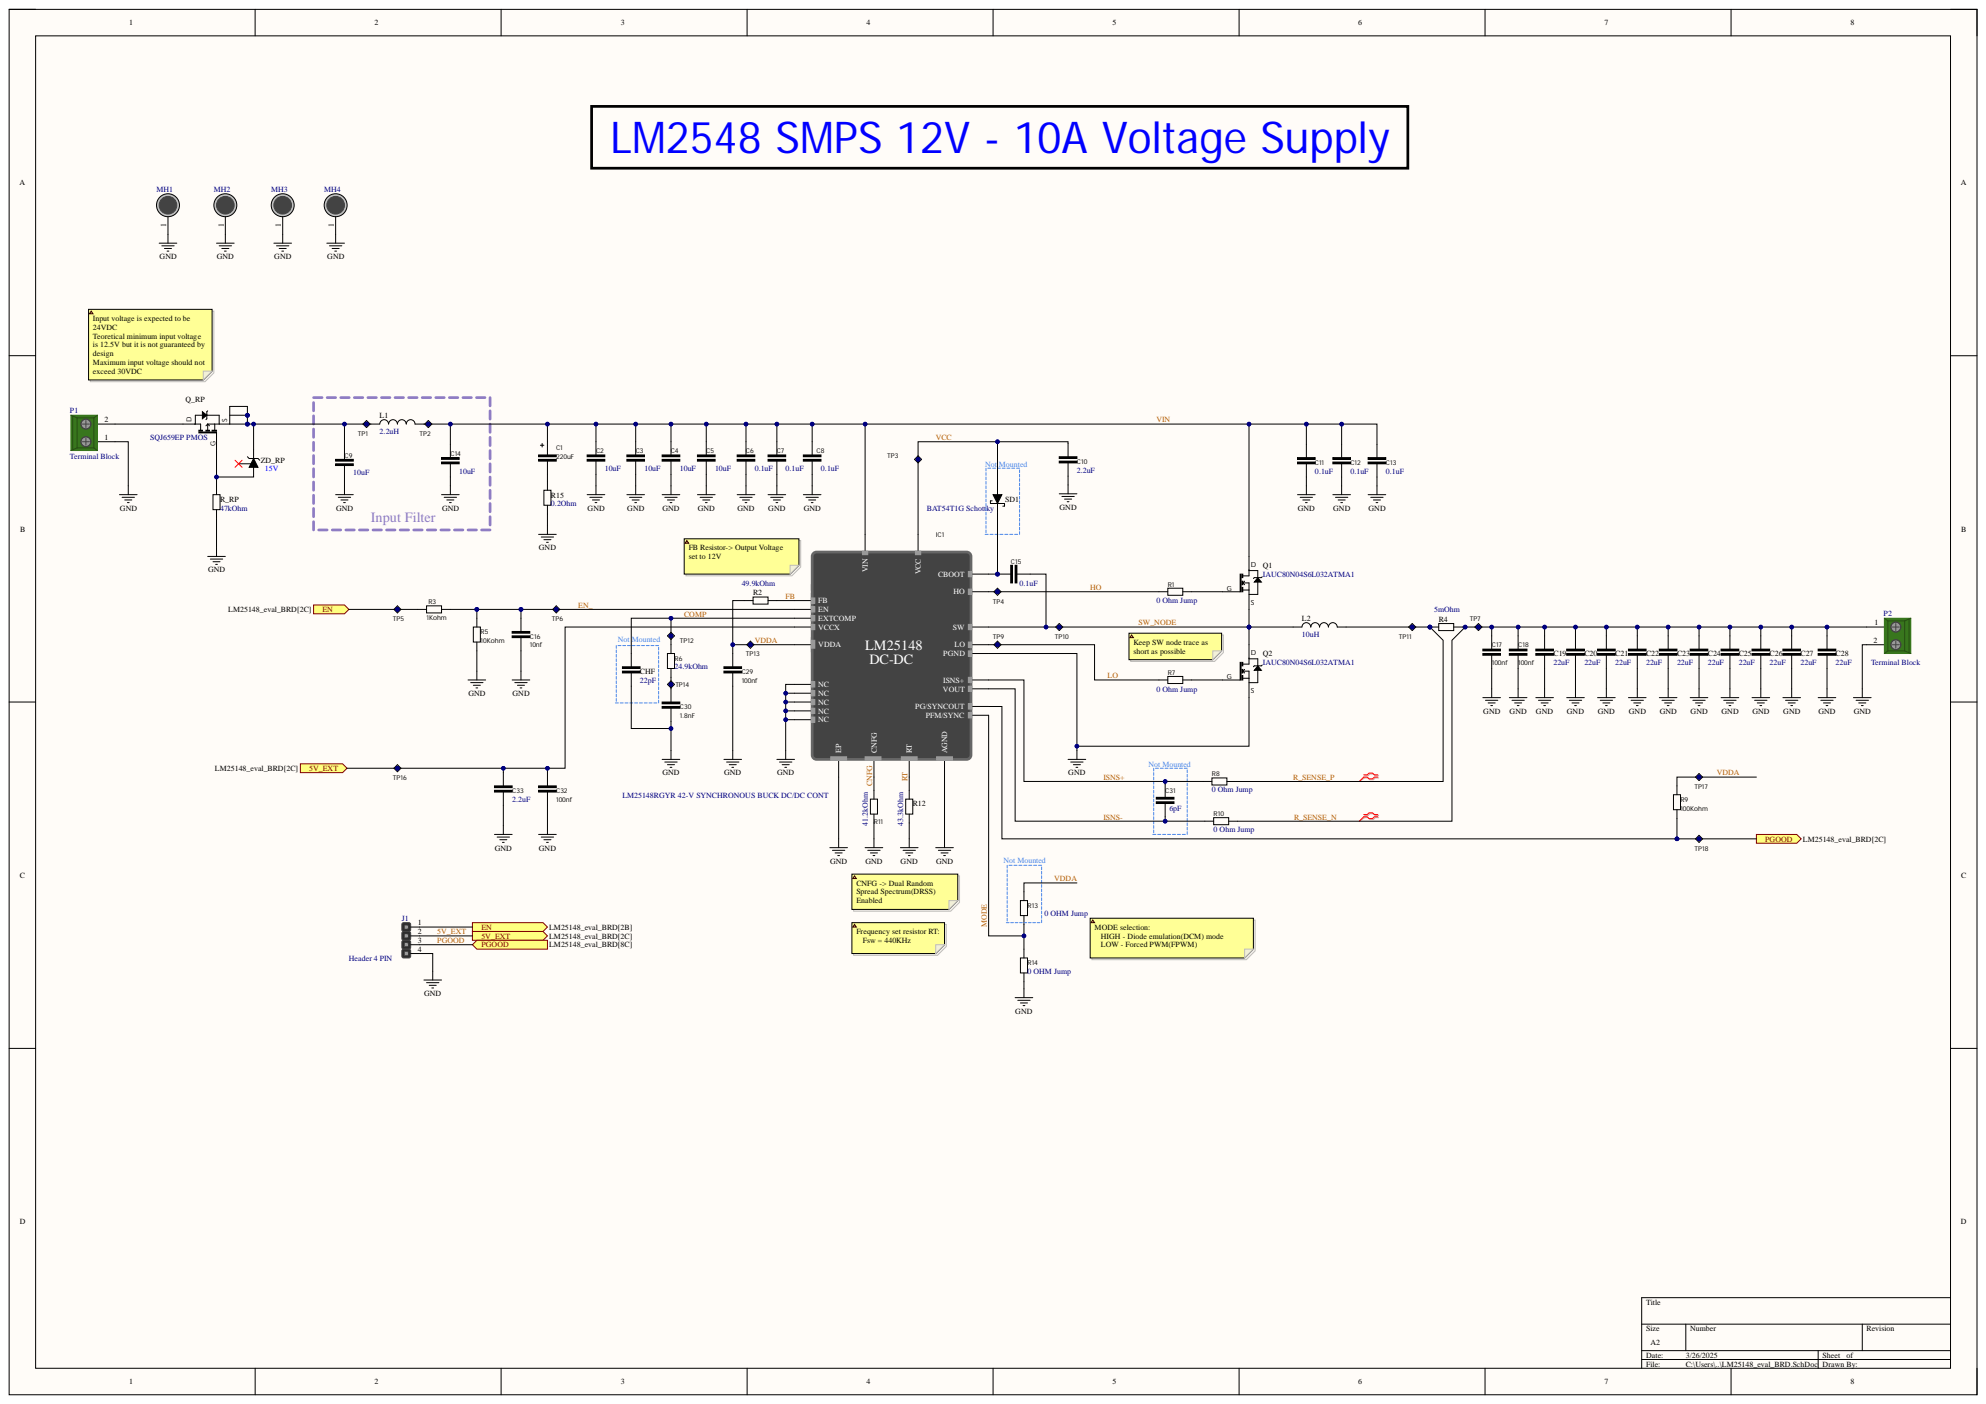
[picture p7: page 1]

Input voltage is expected to be
24VDC
Teoretical minimum input voltage
is 12.5V but it is not guaranteed by
design
Maximum input voltage should not
exceed 30VDC

FB Resistor-> Output Voltage
set to 12V

Keep SW node trace as
short as possible

LM25148RGYR 42-V SYNCHRONOUS BUCK DC/DC CONT

Frequency set resistor RT:
Fsw = 440KHz

MODE selection:
HIGH - Diode emulation(DCM) mode
LOW - Forced PWM(FPWM)

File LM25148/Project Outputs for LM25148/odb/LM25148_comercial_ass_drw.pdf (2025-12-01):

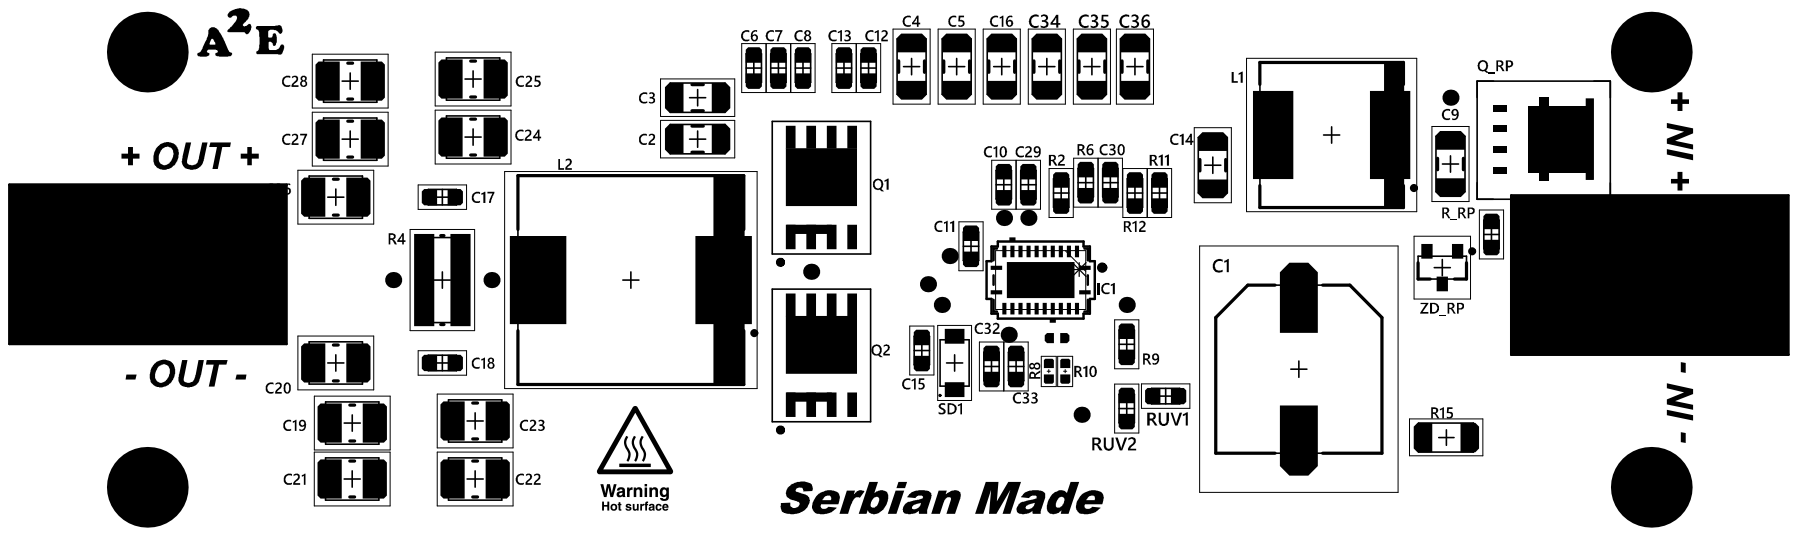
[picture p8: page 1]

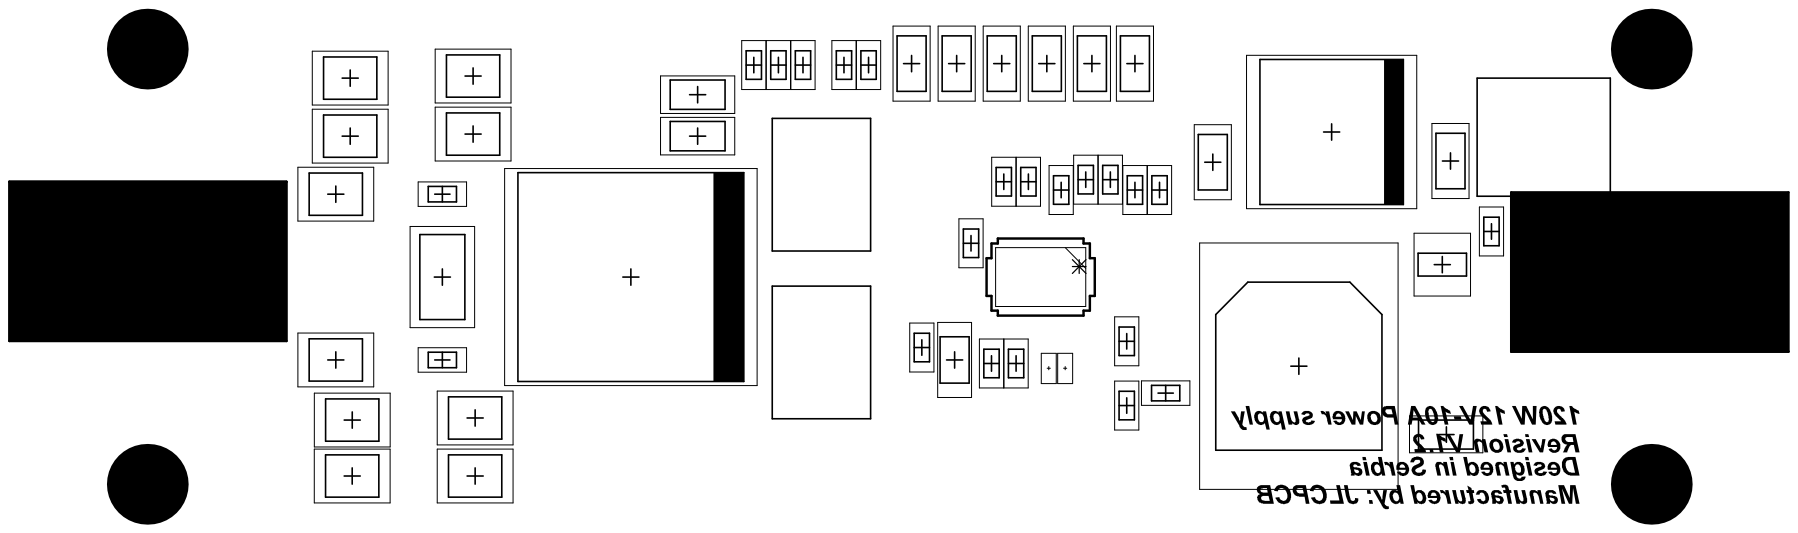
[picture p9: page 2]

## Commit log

2025-03-26 Minor changes and PDF export
    [LM25148.PrjPcb, LM25148_eval_BRD.SchDoc]
2025-03-26 Gerber files and BOM export
    [LM25148.PrjPcb, LM25148_BOM.xlsx, LM25148_BOM_Sprint_porudzbina.xlsx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]
2025-04-23 Device fully tested - Schematic comments added
    [LM25148.PrjPcb, LM25148_eval_BRD.SchDoc]
2025-12-01 Prototype V2 finalized
    [120W_PSU_case_foundation.stl, 120W_PSU_case_top_cover.stl, 2025-10-29 11_46 From Parts Cart JLCPCB Parts.xlsx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]
